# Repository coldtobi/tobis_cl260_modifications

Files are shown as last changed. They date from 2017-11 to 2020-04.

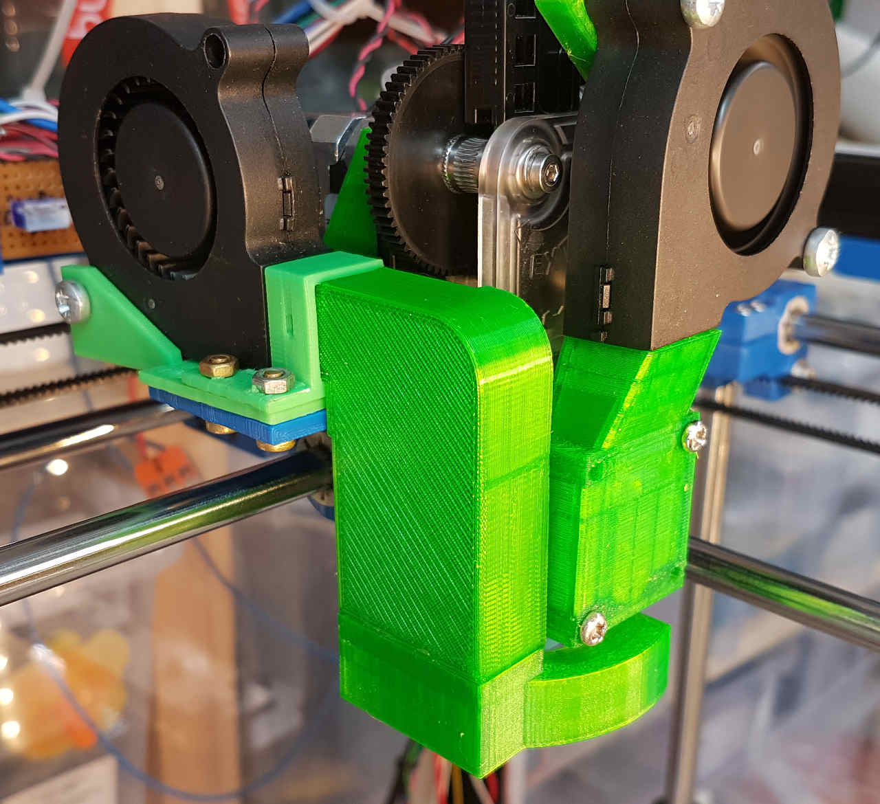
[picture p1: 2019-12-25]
E3D-V6-Titan-Radial-Fan-Heatbreak-Cooler/images/assembly-1.jpg

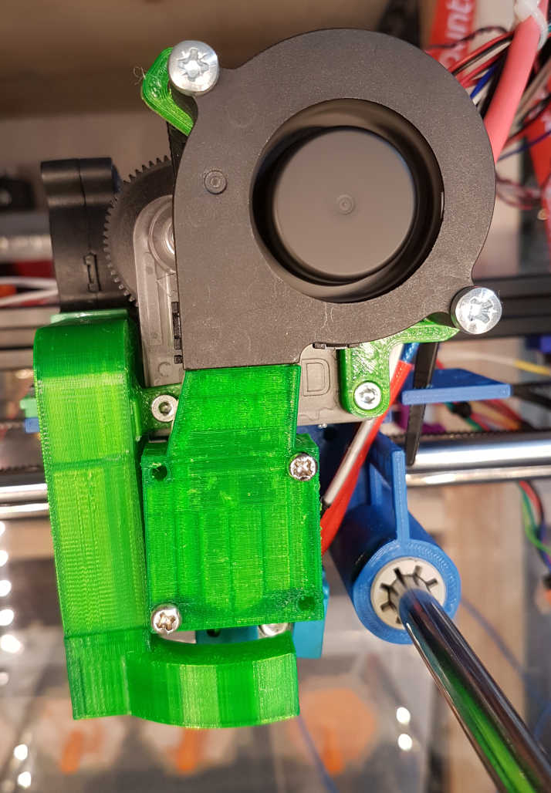
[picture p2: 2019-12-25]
E3D-V6-Titan-Radial-Fan-Heatbreak-Cooler/images/assembly-2.jpg

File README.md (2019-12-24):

# tobis_cl260_modifcations

My modifications done to my CL-260 3D printer.

The CL-260 is a chinese 3D-printer. As the printer is quite cheap, I obtained
the printer with the knowlegde that several things have to be improved
afterwards.

This repository collects all the modifications done in the hope it might
be useful for others too.

## Contributing ##

Contributions are very welcome. Please file issues and create pull-requests.

Please note that the contribution must be under a free and open source license and
and the sources must be suitable to be modified using Free Software (FLOSS).

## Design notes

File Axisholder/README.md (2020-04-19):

# Axisholder for the CL-260 #

License: GPL-2.0+ -- GPL Version 2.0 or later.

    Copyright 2017 Tobias Frost <tobi at coldtobi.de>

    This program is free software; you can redistribute it and/or modify
    it under the terms of the GNU General Public License as published by
    the Free Software Foundation; either version 2 of the License, or
    (at your option) any later version.

    This program is distributed in the hope that it will be useful,
    but WITHOUT ANY WARRANTY; without even the implied warranty of
    MERCHANTABILITY or FITNESS FOR A PARTICULAR PURPOSE.  See the
    GNU General Public License for more details.

    You should have received a copy of the GNU General Public License along
    with this program; if not, write to the Free Software Foundation, Inc.,
    51 Franklin Street, Fifth Floor, Boston, MA 02110-1301 USA.

The complete GPL License text should be part of this repository.

For the avoidance of doubt, "program" can be replaced with "work" in
the license grant above.

## CAD Model ##

The CAD model can be opened using FreeCAD. It was developed using version 0.17
on Debian. Version 2 was designed with 0.18.4.

The CAD model ist structured in 3 parts: Design files, Assembly and Printables.
The first section are the "raw" designs, suitable for modifications, the assembly
section shows the complete assembled parts and the printables show the parts that you
need to print (the numbers at the end say  how often you gonna need it)

## BOM ##

| Quantity | Part | Comment |
|---|---|---|
| | *Printed Parts*  (names from the CAD model) | |
| 2 | printable/X-Axis | |
| 2 | printable/Y-Axis | |
| 4 | printable/Belt_Tightener | |
| 4 | printable/Clamps | |
| | *Nuts and Bolts* | |
| 18 | M3 metal inserts (M3, OD=4.2 mm, lenght 3mm) | e.g https://tinyurl.com/y9mz845h, 22 in Version 2 |
| 16 | M3x15 hex screws | |
| 2 | M3 screws for endstop activation | Only Version 1 |
| 4 | M3 nut | Only Version 1 |
| 4 | M3x~25mm screw (for the belt tightener system) | |
| 4 | M3x~25mm screw (for the belt tightener system) | |
| 4 | M3 set screws  (to clamp the IGUS) | Only Version 2 |

## Assembly ##

The metal inserts are ment to be "melt" into the main parts of the axisholder.
Put on a screw, heat up the screw and push into the plasic part. Put them on the opposite
site of the clamp and they will not be pulled out by the forces of the screw.
(See the FreeCAD assembly part for an illustration)

The remaining 2 inserts are for the one of the two holes on the "backside" of the main
part. It can then hold a screw suitable to activate the endstopa

## Version 2 ##

Version 2 has been remodeled to be a bit smaller than Version 1, to avoid that
the belt pulls upward at the edges of the bed. Also, a set screw allows
fixation of the IGUS bushings to allow a more loose fit of them.

Version two is fully parametric using a FreeCAD Spreadsheet for all dimensions.

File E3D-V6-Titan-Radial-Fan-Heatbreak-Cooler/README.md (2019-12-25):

# E3D-V6-Titan-Radial-Fan-Heatbreak-Cooler #

License: GPL-2.0+ -- GPL Version 2.0 or later.

    Copyright 2019 Tobias Frost <tobi at coldtobi.de>

    This program is free software; you can redistribute it and/or modify
    it under the terms of the GNU General Public License as published by
    the Free Software Foundation; either version 2 of the License, or
    (at your option) any later version.

    This program is distributed in the hope that it will be useful,
    but WITHOUT ANY WARRANTY; without even the implied warranty of
    MERCHANTABILITY or FITNESS FOR A PARTICULAR PURPOSE.  See the
    GNU General Public License for more details.

    You should have received a copy of the GNU General Public License along
    with this program; if not, write to the Free Software Foundation, Inc.,
    51 Franklin Street, Fifth Floor, Boston, MA 02110-1301 USA.

The complete GPL License text should be part of this repository.

For the avoidance of doubt, "program" can be replaced with "work" in
the license grant above.

You can find the "original" git repository on [github].

## What is this?

This is an adapter to allow to mount a radial fan to the fan shroud of a 
E3D-V6 using a [titan] as extruder.

As radial fans are more powerful to work against resistance (e.g a fanduct)
this adapter improves the cooling of the heat break, working against possible
jams due to that. (and of course the fan is bigger :)

This adapter should work with every printer that supports the Titan, but note that
the thickness is 12 mm while your axial fan might be around 7 mm.

I use it on my CL-260 together with my Titan mod, also available in this repo
and on thingiverse: [titan-carrier]

## CAD Model ##

The CAD model can be opened using FreeCAD. It was developed using version 0.18
on Debian. 

The CAD model ist structured in 4 parts: Design, Printables, Assembly and 3rd-Party parts.
The first section are the "raw" designs, suitable for modifications. it also shows 
the complete assembly.

The printables section show the parts that you need to print in (IMHO) the recommendated
orientation on the print bed.

The Assembly section shows an example assembly with my titan carrier.

(the 3rd part, 3rd party models is described below)

### Parts and Printing ###

#### Fanattachment-Titan ####

This part allows that the radial fan be mounted on the Titan. It uses two screws of
the titan assembly for that. You possibly need to replace the Titan screws with bit 
larger ones. 

The fan is assembled using a M4x20mm screws with hex nuts going into the part. One of the 
holes is slotted to allow for different fan types, you probably want to add some glue
to fix the hex nuts when assembled.

Prints without support. 

#### Fanadapter-30mm-Radial ####

This screws to the original E3D V6 fan shroud.
The radial just fan slides into the top part.

Prints without support. 

## 3rd Party Models ##

The FreeCAD Model may also contain a few external objects, listed below with their license:
Those model are only used for illustration, so they are not "derived" work and not subject
to the GPL license of the remaining work.

The Titan assembly model has been modified to have the mirrored version and the
stepper motor / mounting bracket removed. 

You can find the parts in the "3rd Party Models" Group of the FreeCAD file and as a subfolder
in the git repository as source. 

| Part | License | Author | Source |
|---|---|---|---|
| E3D_v6_To_Spec | CC BY 3.0 | lXGaimMasterXl | https://www.thingiverse.com/thing:341689 |
| 50mm radial fan | CC BY 3.0 | Brendon Tower  | https://www.thingiverse.com/thing:2717523 |
| Titan Assembly | GPL 3.0+ | E3D | https://files.e3d-online.com/Titan/ASM_EX_THUMB_SCREW.stp |
| E3DV6 Fan Duct | GPL 2.0 | joshuarowley42 |  https://www.thingiverse.com/thing:340312 |

## References ##

- [github] https://github.com/coldtobi/tobis_cl260_modifications
- [titan-carrier] https://www.thingiverse.com/thing:4065490
- [titan] https://e3d-online.com/titan-extruder

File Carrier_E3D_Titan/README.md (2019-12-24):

# CL-260: Carrier and Fan Assembly for E3D's Titan Extruder #

License: GPL-2.0+ -- GPL Version 2.0 or later.

    Copyright 2019 Tobias Frost <tobi at coldtobi.de>

    This program is free software; you can redistribute it and/or modify
    it under the terms of the GNU General Public License as published by
    the Free Software Foundation; either version 2 of the License, or
    (at your option) any later version.

    This program is distributed in the hope that it will be useful,
    but WITHOUT ANY WARRANTY; without even the implied warranty of
    MERCHANTABILITY or FITNESS FOR A PARTICULAR PURPOSE.  See the
    GNU General Public License for more details.

    You should have received a copy of the GNU General Public License along
    with this program; if not, write to the Free Software Foundation, Inc.,
    51 Franklin Street, Fifth Floor, Boston, MA 02110-1301 USA.

The complete GPL License text should be part of this repository.

For the avoidance of doubt, "program" can be replaced with "work" in
the license grant above.

You can find the "original" git repository on [github].

## What is this?

This is an modifcation for the CL260 from bowden extruding to direct extruding
using a E3D Titan extruder assembly [titan] and a pancake nema 23 stepper motor [stepper]

When shopping for the Titan: You will need the Mirrored version!

Note as the Titan Aero is not a perfect fit for the CL-260 this mod employs the
original Titan.

This design works best with my other parts for the CL-260, e.g I recommend to use
the Axis Holder [axisholder] to avoid mechanical interference.

## CAD Model ##

The CAD model can be opened using FreeCAD. It was developed using version 0.18
on Debian. 

The CAD model ist structured in 3 parts: Design, Printables and 3rd-Party parts.
The first section are the "raw" designs, suitable for modifications. it also shows 
the complete assembly. 

The printables section show the parts that you need to print in (IMHO) the recommendated
orientation on the print bed.

(the 3rd part, 3rd party models is described below)

### Parts and Printing ###

#### XY-Carrier ####

This is the main part of the carrier. It is designed to hold two LM8UU bearings per axis.
It might be that you need to fixate the bearings with a grub screw, if they slide out
by themselves or you might need to tune in the tolerances accordingly in the CAD. 

Most of the titan assembly and fan assembly is done with M3 screws, many uses
metal inserts, e.g [metal inserts].

There are a lot of extra holes to have a possiblity to mount extra stuff,
so not every hole is used.

Prints without support. I recommend 3-4 perimeters,  20% infill and a 
layer height of 0.2 mm.

Note that the heater block is rotated by 90°. So if you use the silicon sock
for the E3DV6 (you should!), the E3D logo will be sideways, not facing you.

(Another note: the images shows an alternative cooling for the heatsink.
The files for this will be released soonish.)

##### Bugs / known issues #####

- Grub-Screws for bearing fixations not in the CAD.
- The titan aero holder is only fixated by 2 screws, this
  is leads that the titan can be easily "tilted" by an upward force,
  like a pulling filament. A bit of glue or a manually adding another screw fixes that.
  The original purpose was to support the Piezo Z-probe, but I guess this should
  be implemented otherwise (I have plans for this in the future)

#### (left) Fan Assembly ####

The fan assembly mounts a 50mm radial fan using two parts:
- Clamp1
- Clamp2

##### Clamp1 #####

The flag at the end holds a M4 screw that will fixate the fan.
Together with Clamp2, it is screwed to the XY carrier using M3 screws and nuts.
(For this, the two screws at the edge are sufficient, the one below the fan is not needed.) 

Prints without support. I recommend 2 perimeters,  20% infill and a 
layer height of 0.2 mm.

##### Clamp2 #####

This clamps the fan and adapts to the fanduct.

(There are holes for grub screws for the fan duct, but this should not
be necessary due to the snug fit.) 

Prints without support. I recommend 2-4 perimeters and a layer height of 0.2 mm.

##### Fanduct #####

Straightforward... it slides into Clamp2 and can be screwed to the titan
with a screw. The bottom end then interface to a nozzle.

Prints without support. I recommend 1-2 perimeter, and a layer height of 0.15 - 0.2 mm.

##### Fanduct-Nozzle #####

There are two options for a nozzle, just print yourself one and slide it in.
They should be "friction fit", if not add a dap of glue.

The "small" nozzle has a small bug: when designing the E3D hotend was misplaced
in the CAD by a few mm, so it is not centered on the nozzle. Though it still
works quite well.

I'm still experimenting with the 180° one, so I cant tell which one is better,
but for sure it also depends on what you are going to print. Suggested reading
on [cooling].

Both, The "small" and the "180°" shoud be printed with support, but make
sure to select your slicers "from the build plate only" option.
I recommend 2 perimeters and a layer height of 0.1 - 0.15 mm.

#### (right) Fan Assembly ####

there is currently no right fan assembly, as for me a one-fan solution seems
to be good enough.

However, the clamps from the left one can be mirrored and used for a right fan as well.
If you design a fan duct 

## 3rd Party Models ##

The FreeCAD Model may also contain a few external objects, listed below with their license:
Those model are only used for illustration, so they are not "derived" work and not subject
to the GPL license of the remaining work.

The Titan assembly model has been modified to have the mirrored version and the
stepper motor / mounting bracket removed. 

You can find the parts in the "3rd Party Models" Group of the FreeCAD file and as a subfolder
in the git repository as source. 

| Part | License | Author | Source |
|---|---|---|---|
| E3D_v6_To_Spec | CC BY 3.0 | lXGaimMasterXl | https://www.thingiverse.com/thing:341689 |
| 50mm radial fan | CC BY 3.0 | Brendon Tower  | https://www.thingiverse.com/thing:2717523 |
| titan_aero_holder_v5 | CC BY 3.0 | Frank Jakobsen | https://www.thingiverse.com/thing:2490018 |
| Titan Assembly | GPL 3.0+ | E3D | https://files.e3d-online.com/Titan/ASM_EX_THUMB_SCREW.stp |
| E3DV6 Fan Duct | GPL 2.0 | joshuarowley42 |  https://www.thingiverse.com/thing:340312 |

## References ##

- [github] https://github.com/coldtobi/tobis_cl260_modifications
- [titan] https://e3d-online.com/titan-extruder
- [axisholder] https://www.thingiverse.com/thing:3141984
- [stepper] I'm using a NEMA 17 25mm pancake stepper with 1.8°/step. Make sure that the axle is long enough! (E3D documentation seems to suggest ~22.2mm) Hint: if it is becoming too hot, you can attach a fan to cool it. 
- [metal inserts] available eg. at AliExpress. Outer Diameter around 4.15 mm, lenght 3mm.
 e.g https://tinyurl.com/y9mz845h
- [cooling] http://www.desiquintans.com/coolingtests and http://www.desiquintans.com/coolingtests2

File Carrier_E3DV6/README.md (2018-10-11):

# CL-260: Carrier for E3DV6 #

License: GPL-2.0+ -- GPL Version 2.0 or later.

    Copyright 2018 Tobias Frost <tobi at coldtobi.de>

    This program is free software; you can redistribute it and/or modify
    it under the terms of the GNU General Public License as published by
    the Free Software Foundation; either version 2 of the License, or
    (at your option) any later version.

    This program is distributed in the hope that it will be useful,
    but WITHOUT ANY WARRANTY; without even the implied warranty of
    MERCHANTABILITY or FITNESS FOR A PARTICULAR PURPOSE.  See the
    GNU General Public License for more details.

    You should have received a copy of the GNU General Public License along
    with this program; if not, write to the Free Software Foundation, Inc.,
    51 Franklin Street, Fifth Floor, Boston, MA 02110-1301 USA.

The complete GPL License text should be part of this repository.

For the avoidance of doubt, "program" can be replaced with "work" in
the license grant above.

## CAD Model ##

The CAD model can be opened using FreeCAD. It was developed using version 0.17
on Debian, but parts of the model have been imported from earlier versions of FreeCAD
(the ones without a Body element) 

The CAD model ist structured in 3 parts: Design files, Assembly and Printables.
The first section are the "raw" designs, suitable for modifications, the assembly
section shows the complete assembled parts and the printables show the parts that you
need to print (the numbers at the end say  how often you gonna need it)

(the 4th part, 3rd party models are described below)

The model is still missing the fanducts... the original FreeCAD model broke and I 
still have to reconstruct it... 

### Parts and Printing ###

#### HET 1 ####

This is the main part of the carrier. It can hold one or two LM8UU bearings,
according to your taste.It runs fine with just one, this is the configuration
I'm using.

The metal inserts are ment to be "melt" into this part of the holder).
Put on a screw, heat up the screw and push into the plasic part. 

Printing should be possible without supports; I've used the orientiation as
shown in the "printables" section of the model (and how the stl are exported)

#### HET 2 ####

The second part clamps the E3DV6 to the first part, using 2 screws. The other two holes
take the top screws of the 40x40 fan, which cools the heatsink.

#### FanShroud ####

Well, it goes around the heatsink… It takes the other two screws of the fan to fix everything
together...

#### Clamp ####

The clamp (not shown on the screenshot) was intended to house a piezo for piezo-
based z-homing. I never came around to actually use this…
In other words, you probably won't need it, and it likely needs tweaks to work
for the original purpose. 

#### Fanduct ####

The fanduct in the model is a two piece design: The main body and the outlet.
Unfortunatly the original FreeCAD model broke, so it is only there without the
possiblity to redo. There was also a second fanduct, but its model is damaged
beyond repair in the same FreeCAD file, so it needs to be redesigned later.

However, I'm ousing it only with the (included) Fanduct, so the second one is
optional.

I recommend to use a sleeve for the hotend, to thermally isolate it and prevent
cooling by the airflow.

## 3rd Party Models ##

The FreeCAD Model may also contain a few external objects, listed below with their license:
(Those model are only used for illustration, so they are not "derived" work and not subject
to the GPL license of the remaining work.)
You can find the parts in the "3rd Party Models" Group of the FreeCAD file and as a subfolder
in the git repository as source. 

| Part | License | Author | Source |
|---|---|---|---|
| E3D_v6_To_Spec  | CC BY 3.0 | lXGaimMasterXl | https://www.thingiverse.com/thing:341689 |
| LM8UU | CC BY 3.0 | 3DRap.it | https://www.thingiverse.com/thing:1811769 |
| 50mm radial fan | CC BY 3.0 | Brendon Tower  | https://www.thingiverse.com/thing:2717523 |

## BOM ##

| Quantity | Part | Comment |
|---|---|---|
| | **Printed Parts** (names from the CAD model)  | |
| 1 | printable/HET1 | main part |
| 1 | printable/HET2 | part for clamping the E3DV6 |
| 1 | printable/FanShroud | guiding the air |
| (1) | printable/Clamp | optional. The clamp was intended for holding a piezo, but this feature is untested. |
| 4 | printable/Clamp | |
| | **Nuts and Bolts** | |
| 3-7 | M3 metal inserts (M3, OD=4.2 mm, lenght 3mm)  | e.g https://tinyurl.com/y9mz845h |
| 1 | M3x?? hex screws | fanshroud 1 mounting |
| 2 | M3x?? hex screws | HET2 -> HET1 mounting |
| (4) | M3x?? hex screws | clamp mounting |
| | **other parts** | |
| | 40x40 mm Fan with its screws | |
| 2-4 | IGUS 15mm Linear bearings | There is place for 2 in series, but it also works with just one per axis.  |

## TODO ##

- Illustrate the screws and inserts in the CAD
- Reconstruct the fanducts.
- Make the Piezo thing (and make it working).

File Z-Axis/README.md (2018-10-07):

# Z-Axis Mod #

License: GPL-2.0+ -- GPL Version 2.0 or later.

    Copyright 2017 Tobias Frost <tobi at coldtobi.de>

    This program is free software; you can redistribute it and/or modify
    it under the terms of the GNU General Public License as published by
    the Free Software Foundation; either version 2 of the License, or
    (at your option) any later version.

    This program is distributed in the hope that it will be useful,
    but WITHOUT ANY WARRANTY; without even the implied warranty of
    MERCHANTABILITY or FITNESS FOR A PARTICULAR PURPOSE.  See the
    GNU General Public License for more details.

    You should have received a copy of the GNU General Public License along
    with this program; if not, write to the Free Software Foundation, Inc.,
    51 Franklin Street, Fifth Floor, Boston, MA 02110-1301 USA.

The complete GPL License text should be part of this repository.

For the avoidance of doubt, "program" can be replaced with "work" in
the license grant above.

## CAD Model ##

The CAD Model can be opened using FreeCAD. It was developed using version 0.17
on Debian. It should give you an idea about the assembly and function.

## BOM ##

(Please make sure to check the CAD, the table might have errors.)

| Quantity | Part | Comment |
|---|---|---|
| | * Metal parts * | |
| 1 | Main Aluminium plate (270x385x8 mm) | |
| 2 | Mounting Plates (270x50x6 mm) | |
| 4 | Connecting Braces (320x30x5 mm) | |
| 3 | Distance Blocks for glass mounting (50x30x6mm) | |
| 3 | Clamps for Glass (U-Profile) 15x15x2 mm len=40 mm | See Bugs |
| | * Bolts and Nuts * | |
| 8 | Cylindrical Head, M3x16 (hex key) | to mount threadnut |
| 3 | Cylindrical Head, M4x6 (hex key) | glass-clamps |
| 16 | Cylindrical Head, M4x20 (hex key) | to mount LMK10UU |
| 4 | Cylindrical Head, M3x40 -- to mount the NEMA17 to plate | not in CAD |
| 19 | Countersunk Head, M5x16 | M5x18 might work too |
| 3 | Countersunk Head, M5x50 | bed-leveling |
| 8 | Nuts M3 | |
| 16 | Nuts M4 | |
| 19 | Nuts M5 | |
| 3 | Knurled Nut M5 (DIN 466) | internet search for DIN 466 |
| | * Rods, Threads, Linear Bearings, ... | |
| 2 | LMK10UU | 4 needed, 2 recycled |
| 1 | Threaded Rods with matching nut | |
| 2 | Linear Shaft (10mm) | 2 needed, 1 recycled |
| | * Printed Parts (not in the CAD) | |
| 2 | Holder for Stepper Motors | File: Motorhalter.fcstd |
| | * Others * (some not in the CAD ) | |
| 1 | Glassplate 255x255x5 mm | Borosilicate glass recommended to avoid cracking due to thermal stress. |
| 1 | Heatbed MK3 Aluminium 3.2 mm thick | http://reprap.org/wiki/PCB_Heatbed#MK3_ALU-Heatbed_Dual_Power |
| 1 | NEMA 17 Stepper Motor + Cable. | 17HS4401 <== I ordered one of those |
| 1 | A4988 Polulu Stepper Driver Module | (optional) |
| | * Recycled Parts * (from the CL-260 kit) | |
| 3 | Springs | |
| 2 | LMK10UU | |
| 1 | Threaded Rod + Nut | make sure to order exact the one from the kit or get two! |

### Recycled parts and other notes ###

For the recyled parts, please make sure to order matching parts. In doubt,
spend a few extra bucks and disregard the recycled ones. It is important to
have identical ones.

As the Heatbed is not really great, I've replaced it with a metalcore PCB one.
While the regular one should also work with the design, I recommend to get one
too.

I'm using 2 stepper driver modules. The RAMP can drive on Z two steppers with
the same driver, but only at half power. Not tried if that is enough juice, so
I recommend to get an extra A4988, just in case.

Regarding the stepper motor: It is ok just to order one and to make them
matching just put the new motor into the X or Y axis and you'll have two
identicals for the Z...

As a general note, check everything as it might contain errors..:
The BOM might be inaccurate, the drawing too...)

## Assembly instructions ##

nothing written here yet..

With the CAD model it should be obvious how to assemble. Note that there are a few threads
to be cut: 3x M5 for the bed-leveling screws and 3x M4 for the glass-clamps.

Precission is key when drilling. I recommend a drill stand for all the drilling
and using proper marking out equipment.

## CL-260 MAX ##

I was told that the CL-260 MAX has different dimensions (400 mm x 400 mm), so this mod might not be 
applicable for this model without tweaks.

## Bugs ##

Nothing without flaws:
- The U-Profiles are not optimal as they take away build space. Better would be an alu flat profile
  in the required dimension.

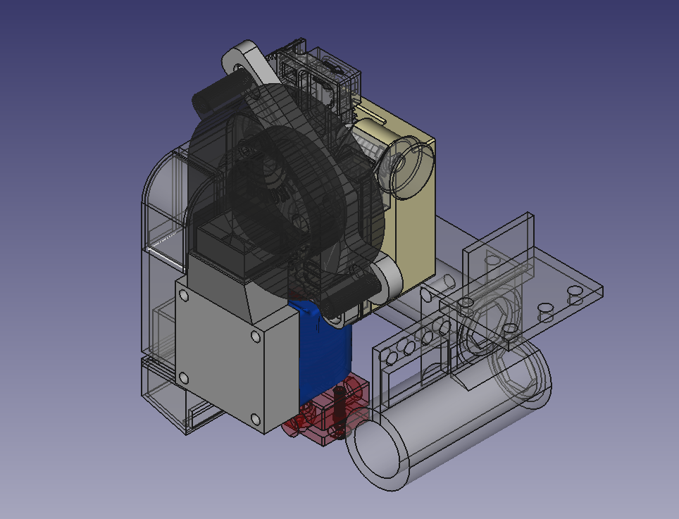
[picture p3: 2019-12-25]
E3D-V6-Titan-Radial-Fan-Heatbreak-Cooler/images/CAD-screenshot.png

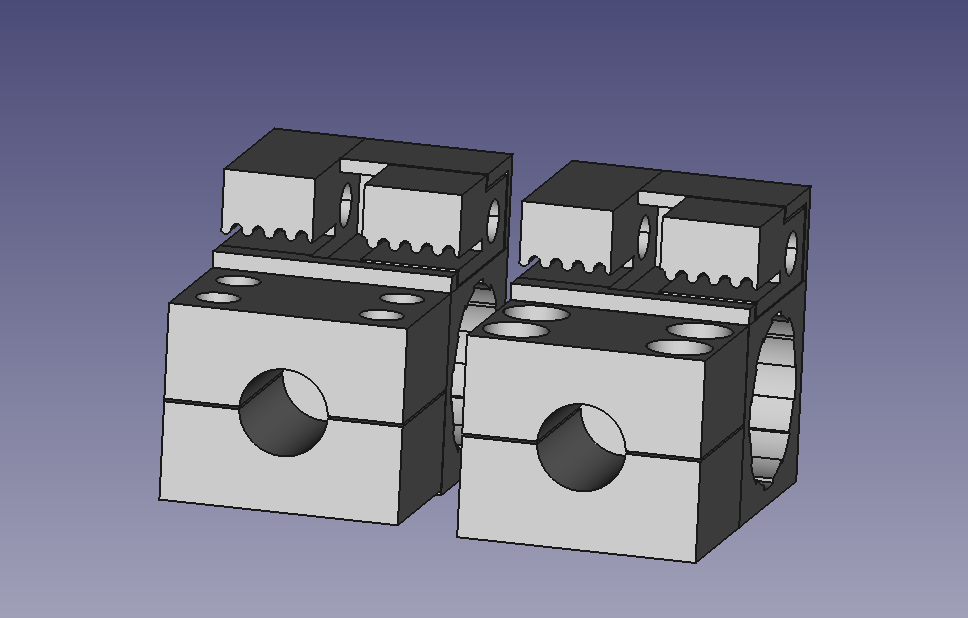
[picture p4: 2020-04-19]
Axisholder/Axisholder_Screenshot_V2.png

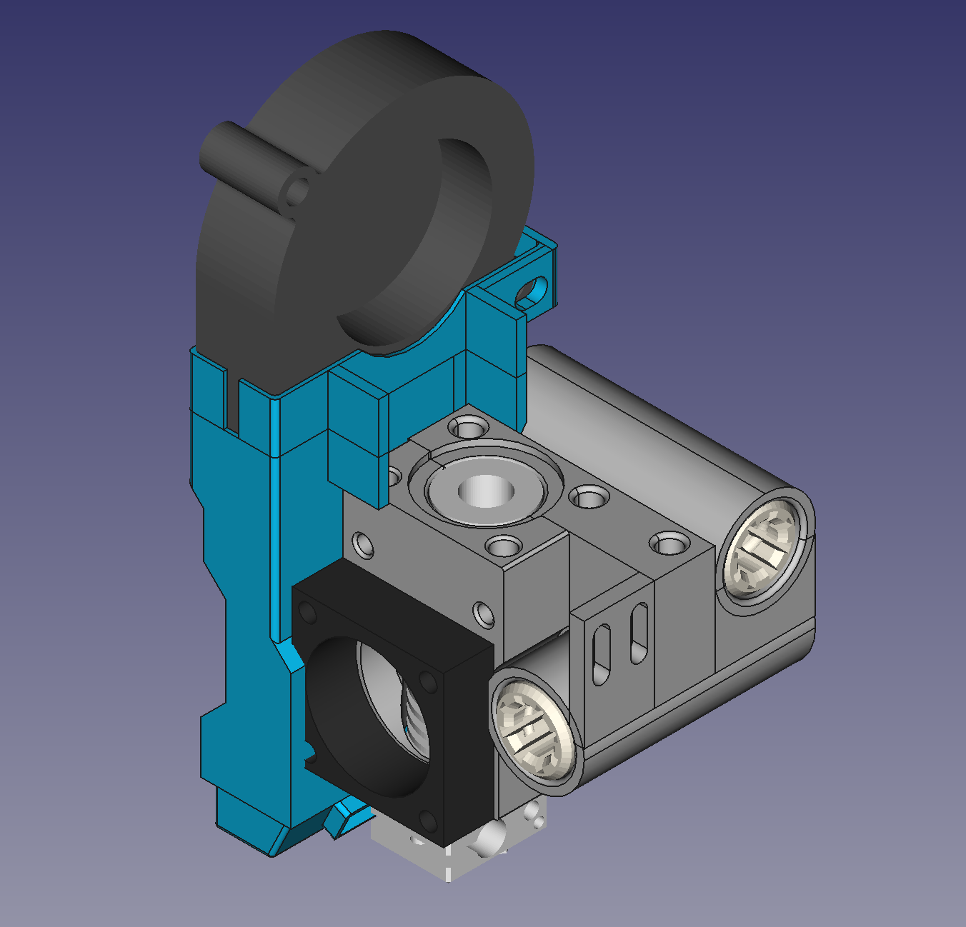
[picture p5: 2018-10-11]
Carrier_E3DV6/Screenshot_Carrier_E3DV6.png

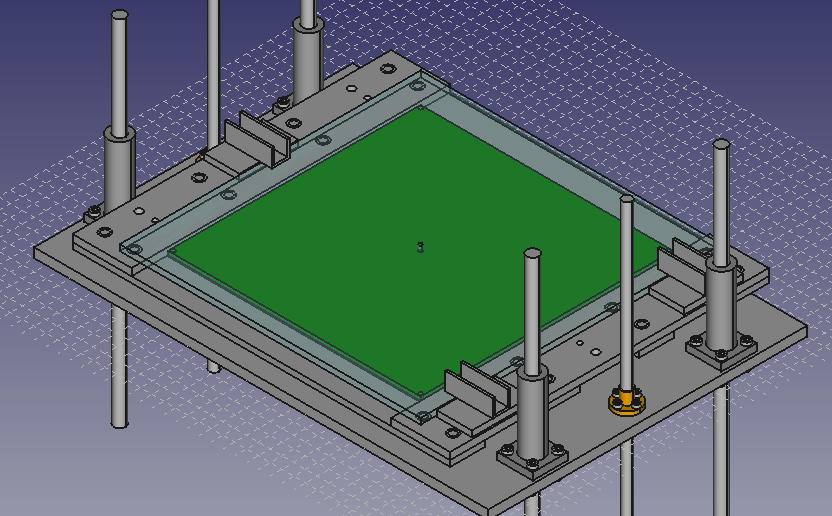
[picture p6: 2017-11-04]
Z-Axis/Z-Axis_CADscreenshot.png

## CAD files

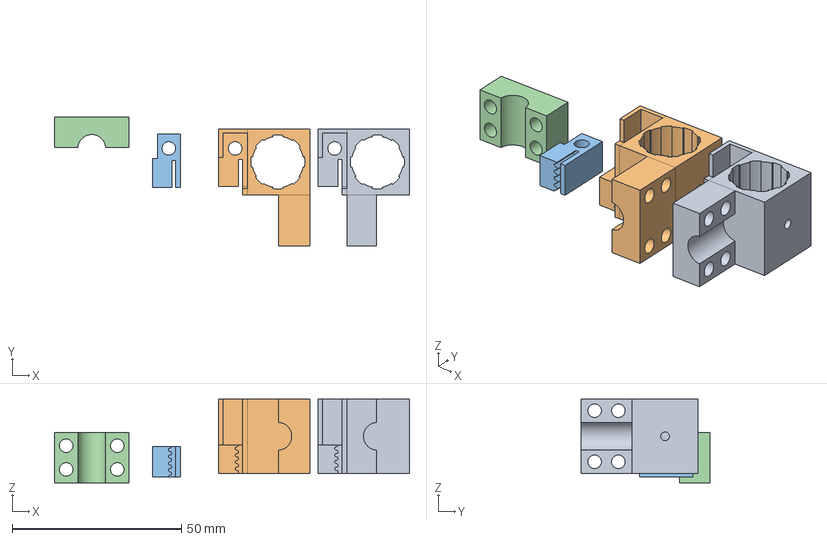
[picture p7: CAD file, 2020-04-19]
Axisholder/Axisholder_v2.fcstd
104.9 x 38.1 x 24.8 mm
Printable_Axisholder_X_Fusion
Printable_Axisholder_Y_Fusion
Printable_Belt Tightener
Clamp001

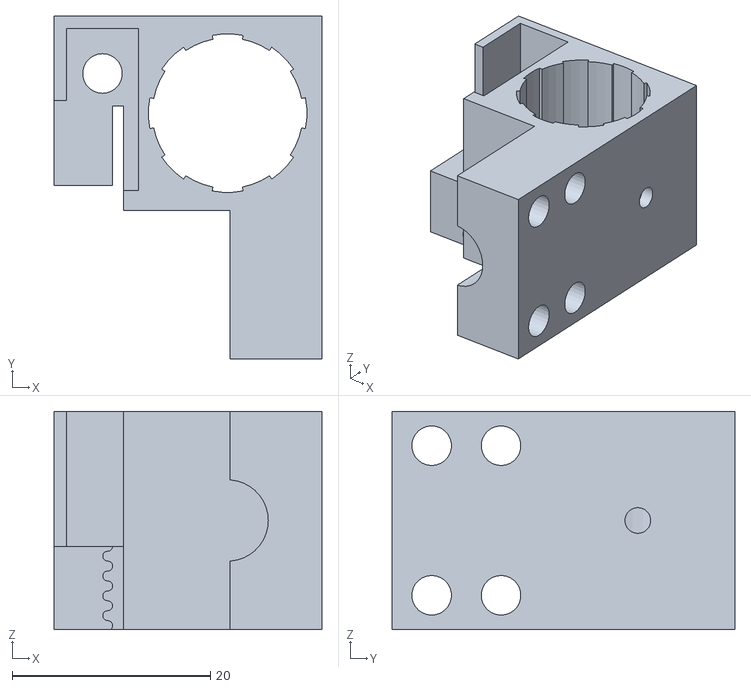
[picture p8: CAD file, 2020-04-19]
Axisholder/STL/V2/Axisholder_Y_V2.stl
27.0 x 34.6 x 22.0

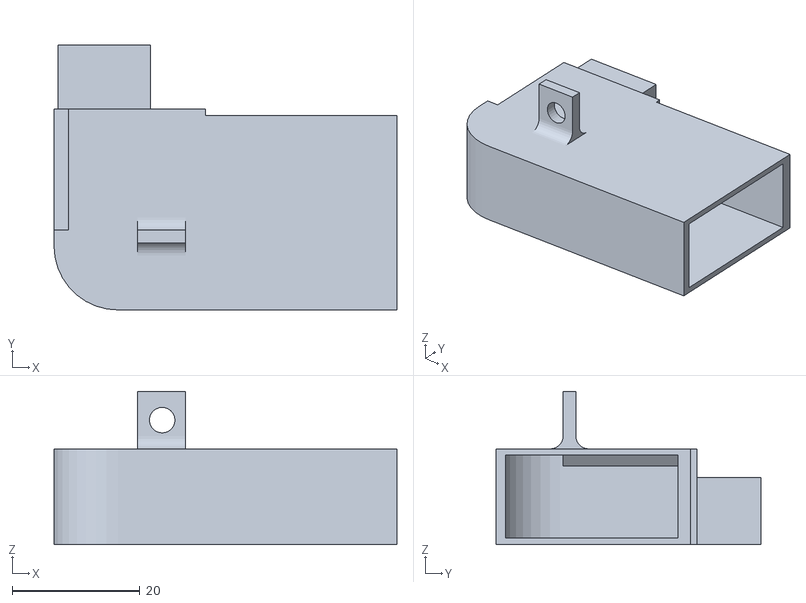
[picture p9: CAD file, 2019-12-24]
Carrier_E3D_Titan/exports/Left-Fan-Fanduct.stl
53.8 x 41.5 x 24.0

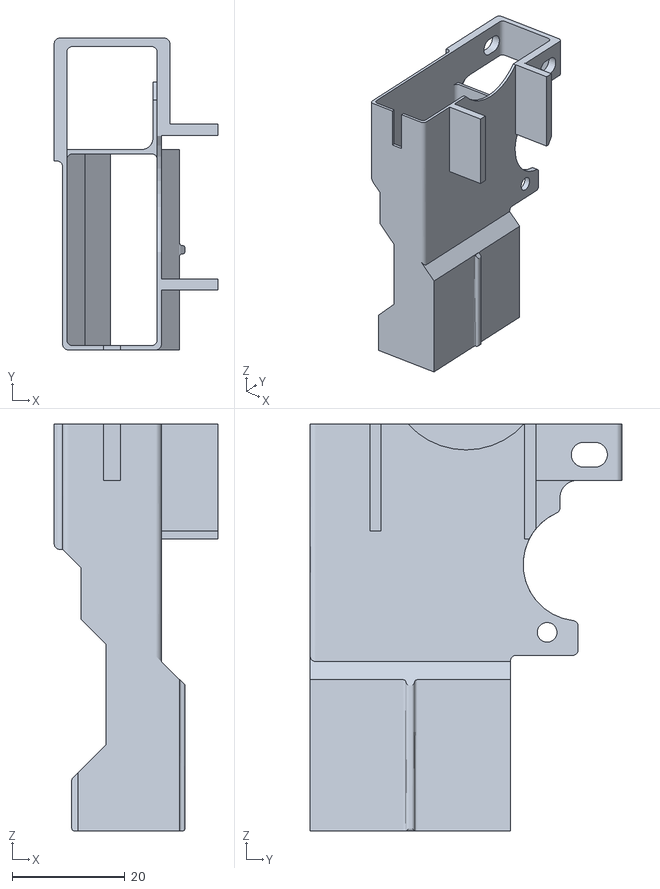
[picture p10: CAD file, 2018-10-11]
Carrier_E3DV6/STL/Fanduct_Body.stl
29.0 x 55.2 x 72.1

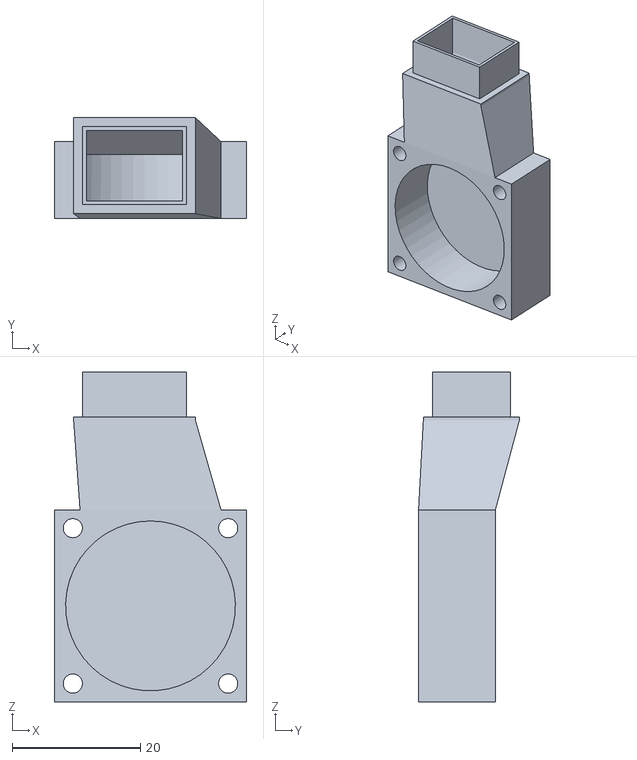
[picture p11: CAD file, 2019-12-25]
E3D-V6-Titan-Radial-Fan-Heatbreak-Cooler/STL/Fanadapter-30mm-Radial.stl
30.0 x 15.8 x 51.5

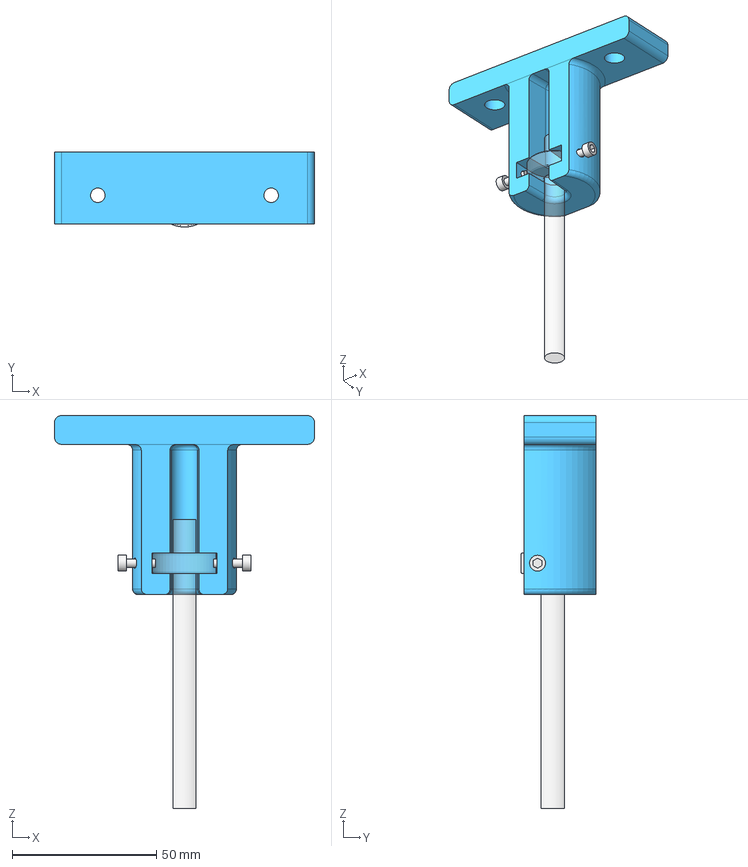
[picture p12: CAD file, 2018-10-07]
Z-Axis-Guide/Z-Axis-Guide.fcstd
90.0 x 26.0 x 136.0 mm
Z-Axis-Guide001
Press-In-Bushing_M3x3mm
Press-In-Bushing_M3x3mm_2
M3x10_Bearing_Fixation
M3x10_Bearing_Fixation_2
BallBearing_608
8mm-Rod

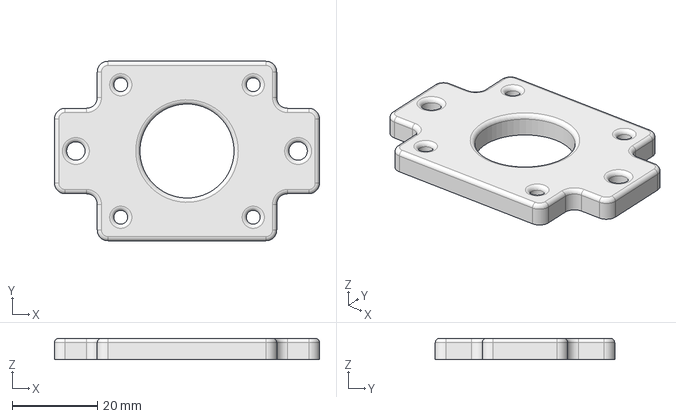
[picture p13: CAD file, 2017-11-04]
Z-Axis/Motorhalter.fcstd
62.0 x 42.0 x 5.00 mm

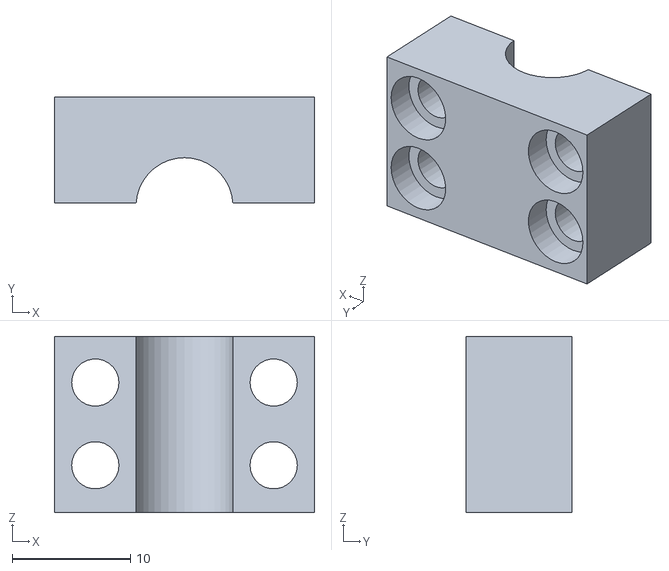
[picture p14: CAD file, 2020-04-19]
Axisholder/STL/V2/Clamp_V2.stl
22.0 x 9.00 x 14.9

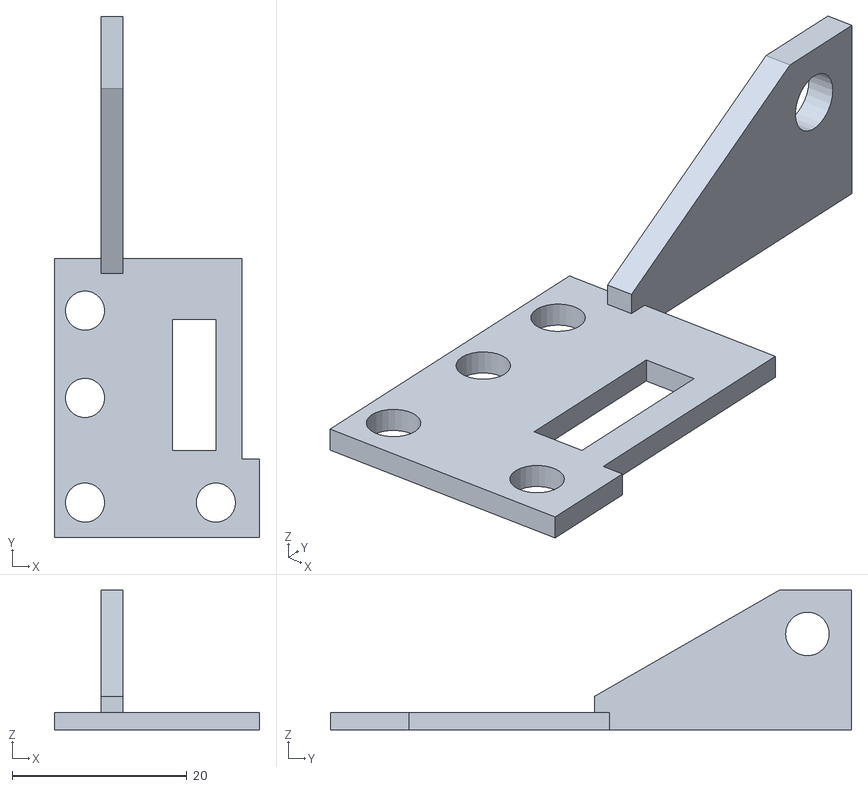
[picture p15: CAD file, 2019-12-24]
Carrier_E3D_Titan/exports/Left-Fan-Clamp1.stl
23.5 x 59.7 x 16.0

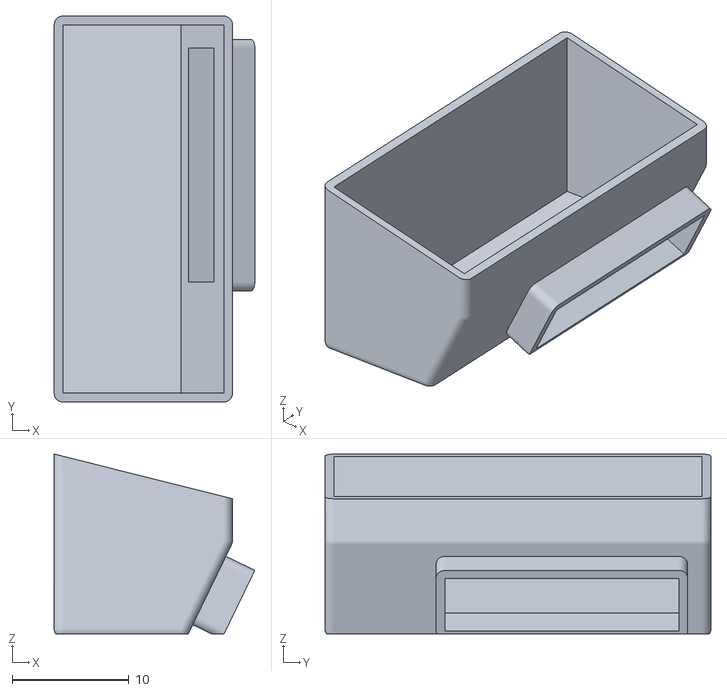
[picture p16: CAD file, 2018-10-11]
Carrier_E3DV6/STL/Fanduct_Outlet.stl
17.2 x 33.0 x 15.4

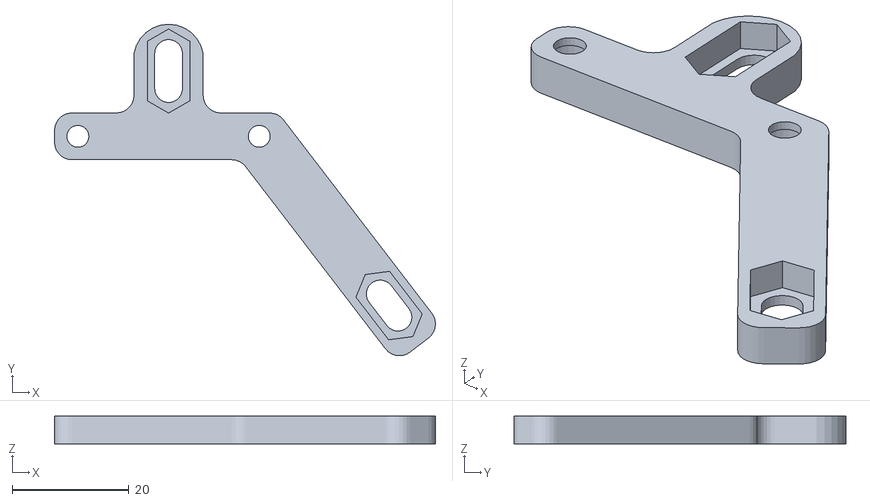
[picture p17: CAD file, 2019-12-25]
E3D-V6-Titan-Radial-Fan-Heatbreak-Cooler/STL/Fanattachment-Titan.stl
65.1 x 56.7 x 4.75

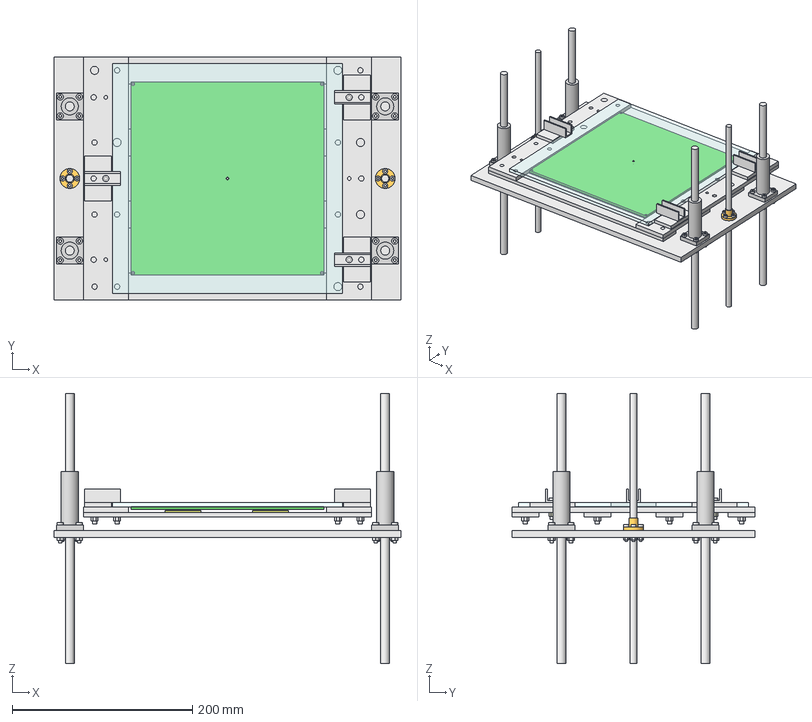
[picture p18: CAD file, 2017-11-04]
Z-Axis/Z-Axis-Mod.fcstd
385.0 x 270.0 x 300.0 mm
Grundplatte mit Bohrungen
LMK10UU001
LMK10UU002
LMK10UU003
LMK10UU004
Gewindemutter
Gewindemutter001
10er Führung
10er Führung001
10er Führung002
10er Führung003
8er Trapezspindel
8er Trapezspindel001
Zylinderkopfschraube M4x20 ISK001
Zylinderkopfschraube M4x20 ISK002
Zylinderkopfschraube M4x20 ISK003
Zylinderkopfschraube M4x20 ISK004
Zylinderkopfschraube M4x20 ISK005
Zylinderkopfschraube M4x20 ISK006
Zylinderkopfschraube M4x20 ISK007
Zylinderkopfschraube M4x20 ISK008
Zylinderkopfschraube M4x20 ISK009
Zylinderkopfschraube M4x20 ISK010
Zylinderkopfschraube M4x20 ISK011
Zylinderkopfschraube M4x20 ISK012
Zylinderkopfschraube M4x20 ISK013
Zylinderkopfschraube M4x20 ISK014
Zylinderkopfschraube M4x20 ISK015
Zylinderkopfschraube M4x20 ISK016
Zylinderkopfschraube M3x16 (DIN912) 001
Zylinderkopfschraube M3x16 (DIN912) 002
Zylinderkopfschraube M3x16 (DIN912) 003
Zylinderkopfschraube M3x16 (DIN912) 004
Zylinderkopfschraube M3x16 (DIN912) 005
Zylinderkopfschraube M3x16 (DIN912) 006
Zylinderkopfschraube M3x16 (DIN912) 007
Zylinderkopfschraube M3x16 (DIN912) 008
Mutter M4 (ISO 4032) 001
Mutter M4 (ISO 4032) 002
Mutter M4 (ISO 4032) 003
Mutter M4 (ISO 4032) 004
Mutter M4 (ISO 4032) 005
Mutter M4 (ISO 4032) 006
Mutter M4 (ISO 4032) 007
Mutter M4 (ISO 4032) 008
Mutter M4 (ISO 4032) 009
Mutter M4 (ISO 4032) 010
Mutter M4 (ISO 4032) 011
Mutter M4 (ISO 4032) 012
Mutter M4 (ISO 4032) 013
Mutter M4 (ISO 4032) 014
Mutter M4 (ISO 4032) 015
Mutter M4 (ISO 4032) 016
Mutter M3 (ISO 4032) 001
Mutter M3 (ISO 4032) 002
Mutter M3 (ISO 4032) 003
Mutter M3 (ISO 4032) 004
Mutter M3 (ISO 4032) 005
Mutter M3 (ISO 4032) 006
Mutter M3 (ISO 4032) 007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

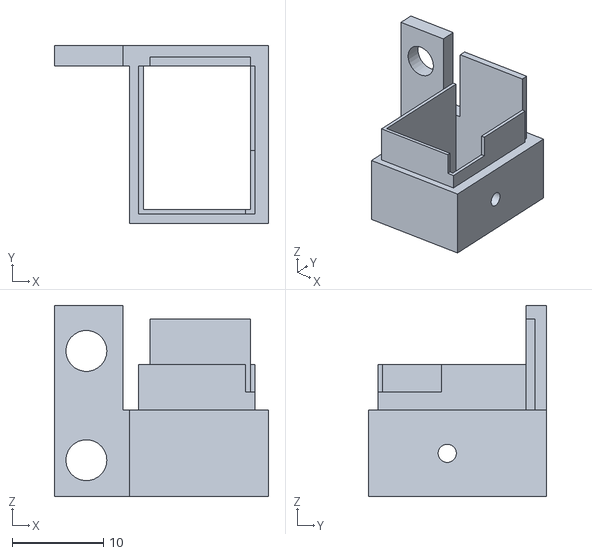
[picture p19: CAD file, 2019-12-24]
Carrier_E3D_Titan/exports/Left-Fan-Clamp2.stl
23.5 x 19.5 x 21.0

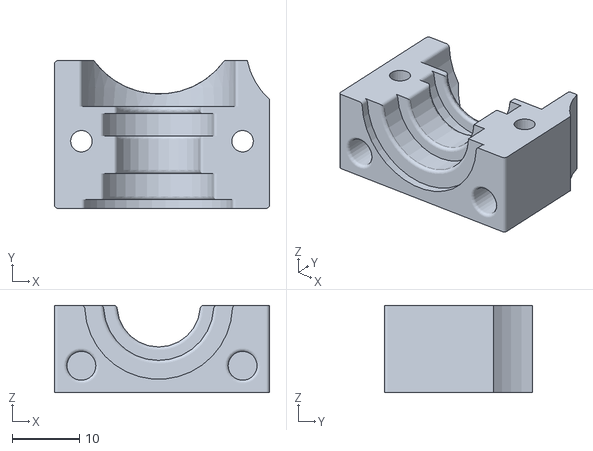
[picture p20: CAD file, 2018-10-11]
Carrier_E3DV6/STL/Carrier_Part2.stl
32.0 x 22.0 x 13.0

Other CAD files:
Axisholder/STL/V2/Axisholder_X_V2.stl
Axisholder/STL/V2/BeltTightener_V2.stl
Carrier_E3D_Titan/exports/Left-Fan-Nozzle-180°.stl
Carrier_E3DV6/STL/Carrier_Part1.stl
Axisholder/Axisholder.fcstd
Axisholder/STL/V1/BeltTightener.stl
Axisholder/STL/V1/Clamps.stl
Axisholder/STL/V1/X-Axis.stl
Axisholder/STL/V1/Y-Axis.stl
Carrier_E3DV6/STL/FanShroud.stl
Carrier_E3D_Titan/exports/Left-Fan-Nozzle-Small.stl
Carrier_E3D_Titan/exports/XY-Carrier.stl
Z-Axis-Guide/Z-Axis_Guide.stl

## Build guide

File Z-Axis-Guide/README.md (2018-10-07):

# Z-Axis guide for the CL-260 #

This parts "holds" the Z-Axis in place from the top position, avoiding the axis
to wobble to much due to the play of my rod-driving nuts.
(Make sure to align the rod, though, the guid only adresses wobble due to the
play of the nut)

## License ##

License: GPL-2.0+ -- GPL Version 2.0 or later.

    Copyright 2017 Tobias Frost <tobi at coldtobi.de>

    This program is free software; you can redistribute it and/or modify
    it under the terms of the GNU General Public License as published by
    the Free Software Foundation; either version 2 of the License, or
    (at your option) any later version.

    This program is distributed in the hope that it will be useful,
    but WITHOUT ANY WARRANTY; without even the implied warranty of
    MERCHANTABILITY or FITNESS FOR A PARTICULAR PURPOSE.  See the
    GNU General Public License for more details.

    You should have received a copy of the GNU General Public License along
    with this program; if not, write to the Free Software Foundation, Inc.,
    51 Franklin Street, Fifth Floor, Boston, MA 02110-1301 USA.

The complete GPL License text should be part of this repository.

For the avoidance of doubt, "program" can be replaced with "work" in
the license grant above.

## CAD Model ##

The CAD model can be opened using FreeCAD. It was developed using version 0.17
on Debian. 

The CAD model ist structured in 3 parts: Design files, Assembly and Printables.
The first section are the "raw" designs, suitable for modifications, the
assembly
section shows the complete assembled parts and the printables show the parts
that you
need to print, in the orientation that I've used to print mine.

## BOM ##

| Quantity | Part | Comment |
|---|---|---|
| | *Printed Parts*  (names from the CAD model)  | |
| 2 | printable/Z-Axis_Guide | |
| | *Nuts and Bolts* | |
| 4 | M3 metal inserts (M3, OD=4.2 mm, lenght 3mm) | e.g https://tinyurl.com/y9mz845h |
| 4 | M3x10 hex screws | |
| | *For assembly to the printer frame* | not in the drawing |
| 4 | M4x10 hex screws | |
| 4 | M4 T-Nuts for your frame | |

## Assembly ##

The metal inserts are ment to be "melt" into the main parts of the main part.
Put on a screw, heat up the screw and push into the plasic part. The assembly
drawing should give you the idea…

## Print Setting ##

I've printed with 3 perimeters and a layer height of 0.25 mm using ABS.
Honeycomb infill was set to 25%.

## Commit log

2017-11-04 Added Z-Axis Mod
    [Motorhalter.fcstd, Z-Axis-Mod.fcstd]
2017-11-04 [Z-Axis] Add Screenshot from CAD
2018-06-25 [Z-Axis-Mod] rename README to README.md
2018-06-25 [Axisholder] Add the axisholder.
    [Axisholder.fcstd]
2018-06-25 [Z-Axis] Add remark to use borosilicate glass...
    normal glass can shatter due to thermal stress
    (but this happens also with outher Z-Axis designs)
2018-10-07 [Z-Axis-Guide] A part to stabilize the Z-Axis from wobbling through driving nut play.
    [Z-Axis-Guide.fcstd, Z-Axis_Guide.stl]
2018-10-07 [Axisholder] Add bushings to illustrate their positions.
    Export STLs for printing without firing up FreeCAD.
    [Axisholder.fcstd, BeltTightener.stl, Clamps.stl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]
2018-10-07 [Z-Axis] Add note about CL-260 MAX
2018-10-11 Add current version, reconstructed from broken FreeCAD file.
    Still missing:
    - Fanduct 1
    - Fanduct 2
    - Illustration with Axisholder.
    [Carrier_Part1.stl, Carrier_Part2.stl, FanShroud.stl]
2018-10-11 Update text and add 50mm fan for illustration
    [Fanduct_Body.stl, Fanduct_Outlet.stl]
2019-12-24 Adding my Titan mod.
    [Left-Fan-Clamp1.stl, Left-Fan-Clamp2.stl, Left-Fan-Fanduct.stl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]
2019-12-25 Add design for the radial fan / heatbreak cooler.
    [Fanadapter-30mm-Radial.stl, Fanattachment-Titan.stl]
2020-04-19 Axisholder V2
    [Axisholder_X_V2.stl, Axisholder_Y_V2.stl, Axisholder_v2.fcstd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]
